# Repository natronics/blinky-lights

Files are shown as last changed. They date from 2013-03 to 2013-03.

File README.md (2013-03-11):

# blinky-lights

My first 555 project, also an example board for [psu-epl](http://psu-epl.github.com/).

It's a small PCB with a [555 timer](http://en.wikipedia.org/wiki/555_timer_IC)
that drives the clock of a shift register/LED driver IC to make a bunch of
LEDs blink in a turn.

CAD files are made with the a free copy of [EAGLE](http://www.cadsoftusa.com/) version 6.3.0.

## Schematic

preview of schematic

## Layout

preview of board

## BOM

 - 1x 555 Timer
 - 1x Allegro A6278EA LED Driver IC
 - 2x 10 μF Capacitor
 - 1x 0.01 μF Capacitor
 - 2x 1k Ω Resistor
 - 1x 4k Ω Resistor
 - 1x 500 Ω Resistor
 - 1x 10 Ω Resistor
 - 1x N Channel MOSFET (TO-92)
 - 8x 3mm LEDs
 - 1x Spare USB cable

# Build Log

## 2013-04-10

Good working breadboard. Schematic and board layout (should) match what is working on my bench.

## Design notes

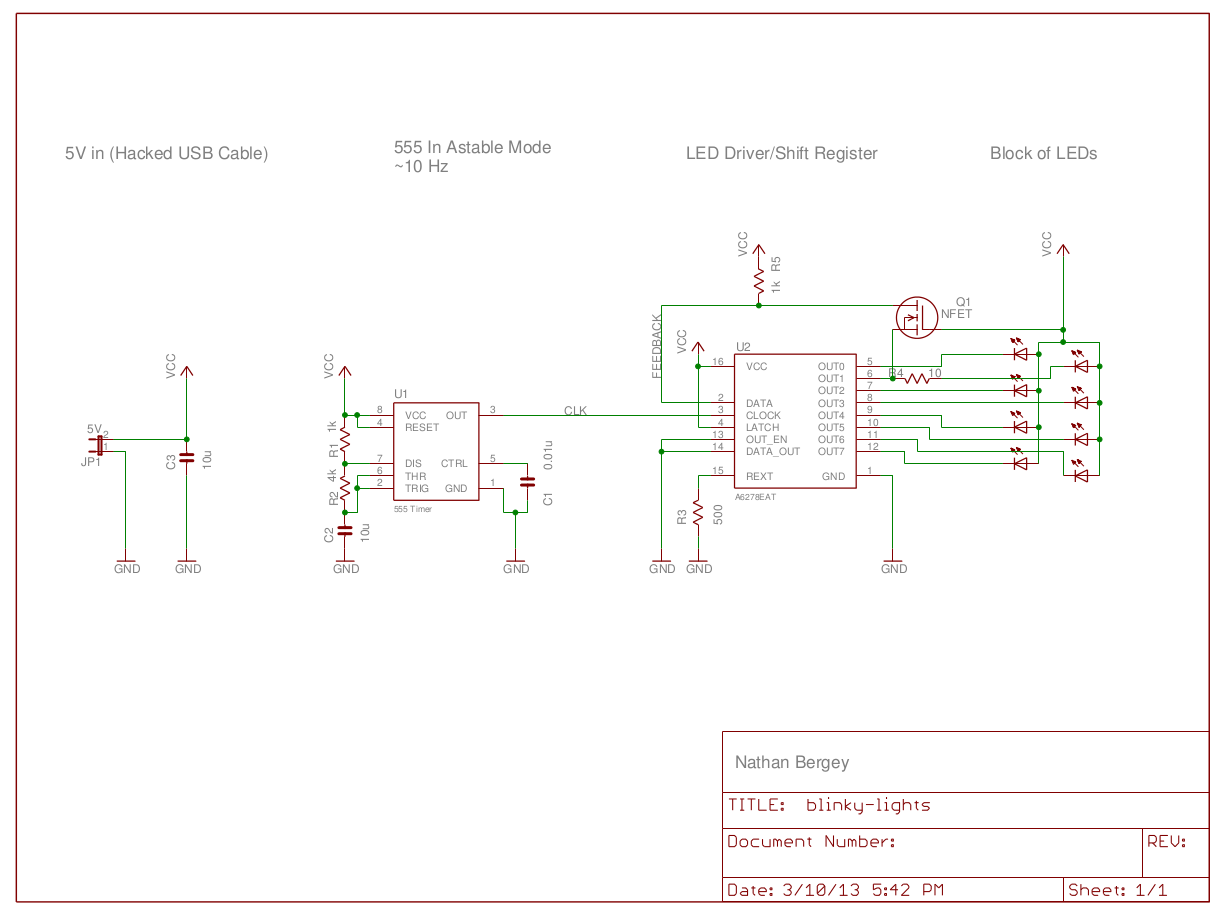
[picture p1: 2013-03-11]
schematic.png

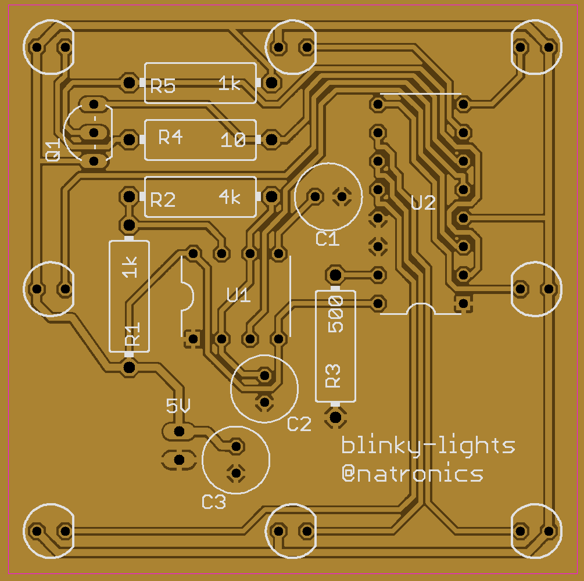
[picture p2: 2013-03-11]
board.png

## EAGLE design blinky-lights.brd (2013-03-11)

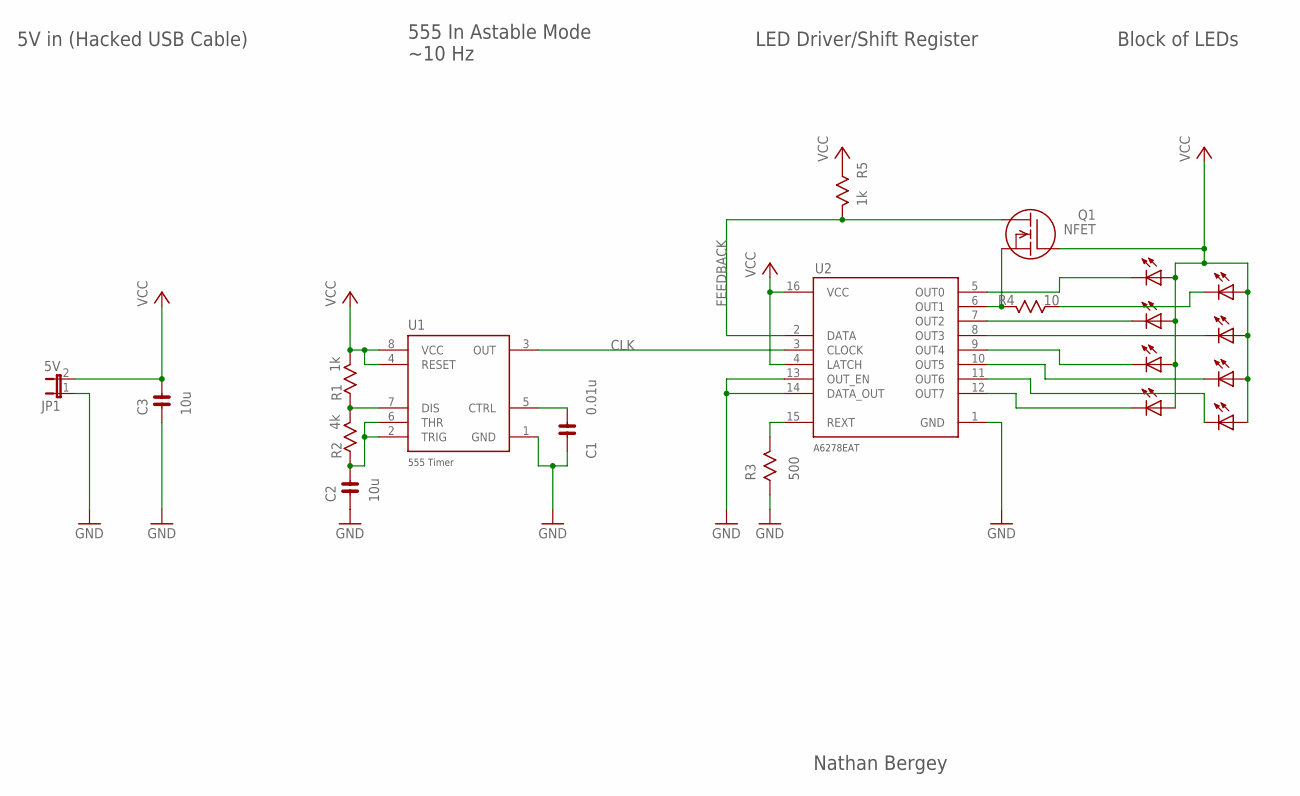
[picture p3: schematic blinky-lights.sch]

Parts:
C1: 0.01u; CAP
C2, C3: 10u; CAP
JP1: 5V; JP1
LED0, LED1, LED2, LED3, LED4, LED5, LED6, LED7: LED3MM
Q1: NFET; TO92-EBC
R1, R5: 1k; V234/12
R2: 4k; V234/12
R3: 500; V234/12
R4: 10; V234/12
U1: 555
U2: A2678EAT; A6278EAT

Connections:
CLK: U1.3 (OUT), U2.3 (CLOCK)
FEEDBACK: Q1.D, R5.2 (C), U2.2 (DATA)
GND: C1.C, C2.C, C3.C, JP1.1, R3.1 (A), U1.1 (GND), U2.1 (GND), U2.13 (OUT_EN), U2.14 (DATA_OUT)
unnamed: LED0.K (C), U2.5 (OUT0)
unnamed: LED2.K (C), U2.7 (OUT2)
unnamed: LED4.K (C), U2.9 (OUT4)
unnamed: LED7.K (C), U2.12 (OUT7)
unnamed: Q1.S, R4.2 (C), U2.6 (OUT1)
unnamed: LED3.K (C), U2.8 (OUT3)
unnamed: LED5.K (C), U2.10 (OUT5)
unnamed: LED6.K (C), U2.11 (OUT6)
unnamed: R1.1 (A), R2.2 (C), U1.7 (DIS)
unnamed: C1.A, U1.5 (CTRL)
unnamed: C2.A, R2.1 (A), U1.2 (TRIG), U1.6 (THR)
REXT: R3.2 (C), U2.15 (REXT)
SENSE: LED1.K (C), R4.1 (A)
VCC: C3.A, JP1.2, LED0.A, LED1.A, LED2.A, LED3.A, LED4.A, LED5.A, LED6.A, LED7.A, Q1.G, R1.2 (C), R5.1 (A), U1.4 (RESET), U1.8 (VCC), U2.4 (LATCH), U2.16 (VCC)

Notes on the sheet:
Nathan Bergey
5V in (Hacked USB Cable)
555 In Astable Mode ~10 Hz
LED Driver/Shift Register
Block of LEDs

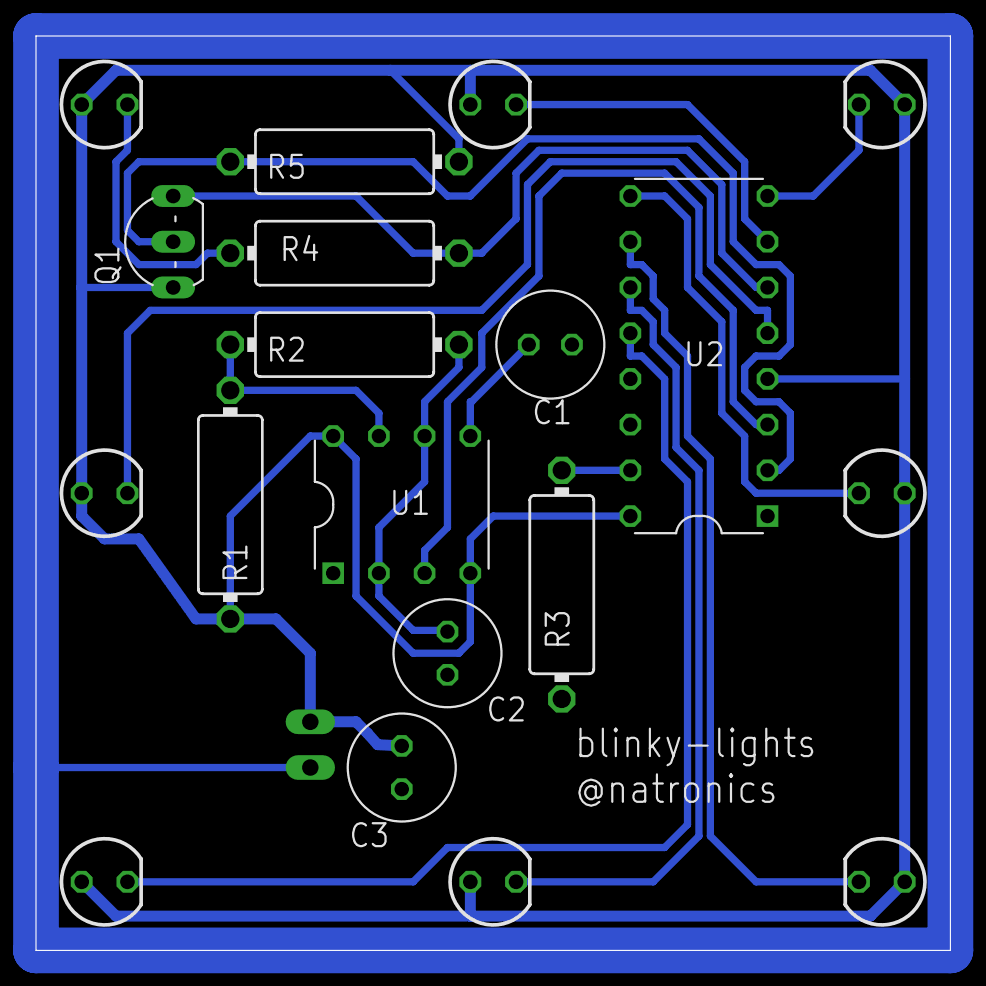
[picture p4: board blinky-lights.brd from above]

Board: 2 copper layers, 50.8 x 50.8 mm, 20 parts (0 on the bottom side), 17 nets.

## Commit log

2013-03-05 part library with LED driver
2013-03-05 555 Timer in parts library
2013-03-05 simple capacitor part
2013-03-05 fixed capacitor simbol
2013-03-05 adding schematic preview
2013-03-05 fixed schematic image uri
2013-03-05 schematic passed ERC
    [blinky-lights.sch]
2013-03-06 Feedback with a NPN transistor and pulldown resistor on DATA line. Also added decoupling capacitor at power in
    [blinky-lights.sch]
2013-03-06 Capacitor Value
    [blinky-lights.sch]
2013-03-06 first pass board layout with not routing
    [blinky-lights.brd, blinky-lights.sch]
2013-03-10 replaced transistor with a fet
    [blinky-lights.sch]
2013-03-10 board layout
    [blinky-lights.brd, blinky-lights.sch]
2013-03-10 minor cleanup on board
    [blinky-lights.brd]
2013-03-10 schematic and board clean up
    [blinky-lights.brd, blinky-lights.sch]
2013-03-10 board clean up, got rid of last airwire
    [blinky-lights.brd, blinky-lights.sch]
2013-03-11 board and schematic cleanup
    [blinky-lights.brd, blinky-lights.sch]
2013-03-11 Finished cleanup and cut a set of gerbers to try and mill
    [blinky-lights_DRILL.xln]
2013-03-11 Added basic BOM
